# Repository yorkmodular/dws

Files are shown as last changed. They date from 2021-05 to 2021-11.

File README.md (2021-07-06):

## DWS - The Diodular Wave Strangler

Proof, if any were needed, that you don't always need a ton of components to make a boring old sine (or triangle, or sawtooth - square waves don't work too well) wave much more interesting. We're going to achieve this with the aid of an op-amp and a bunch of passives (diodes and resistors, mainly)

Here you'll find:

- The Bill of Materials (BOM) - these are the bits you'll need to complete the module.
- The schematic
- Design files for the front panel, should you be seized with a desire to roll your own.

### In use

Twiddle the knobs.

Seriously.

The effectiveness of each of the diode stage pots seems to depend a lot on the settings of the SCALE and SLOPE pots - in some cases, you'll find that only the first four stages have any real effect, whereas in others the later stages will have quite a profound effect instead. Experimentation is the key.

I find that the best results can be obtained from sine and triangle waves, whereas the effects on square waves are minimal at best. The effects on a sawtooth are somewhere in between - in any event, a bit of post-filtering can work wonders for the sound.

A good starting point would be to have the SCALE pot fully counter-clockwise and the SLOPE pot at around 10 o'clock - when adjusting the levels in the diode stages, try and avoid consecutive 'extreme' values.

### Build notes

The build is pretty straightforward - there are no surface-mount or wilfully strange parts, unless you count Schottky diodes.

* R20 can either be a 1k resistor _or_ a 100nF film capacitor. The latter will remove any DC offset in the folded signal - this is what I recommend (ceramic capacitors will work, but I prefer to use film caps for DC offset removal purposes)

* I strongly recommend using Schottky (or germanium) diodes for both the diode stages (D1-D8) and the soft-clipping section (D10, D11) - ideally, the voltage drop for these diodes should be no more than 0.3V - for pre-built modules I use Vishay SD101C-TR diodes, but any small-signal Schottky will do. It's OK to use 1N4148s for the power supply diodes (D13, D14)

* In terms of pots, RV1 to RV8 should be 100k audio taper - linear taper will work fine, but I found that the log taper pots gave me more control. SCALE1 and SLOPE1 pots should be linear taper (10k and 100k, respectively), whilst the OUTPUT_GAIN pot should be 100k audio.

* Reduce the value of R19 if you want more gain.

* The op-amp doesn't need to be anything particularly exotic - I generally use TL084s on pre-builts. TL074 will work just as well.

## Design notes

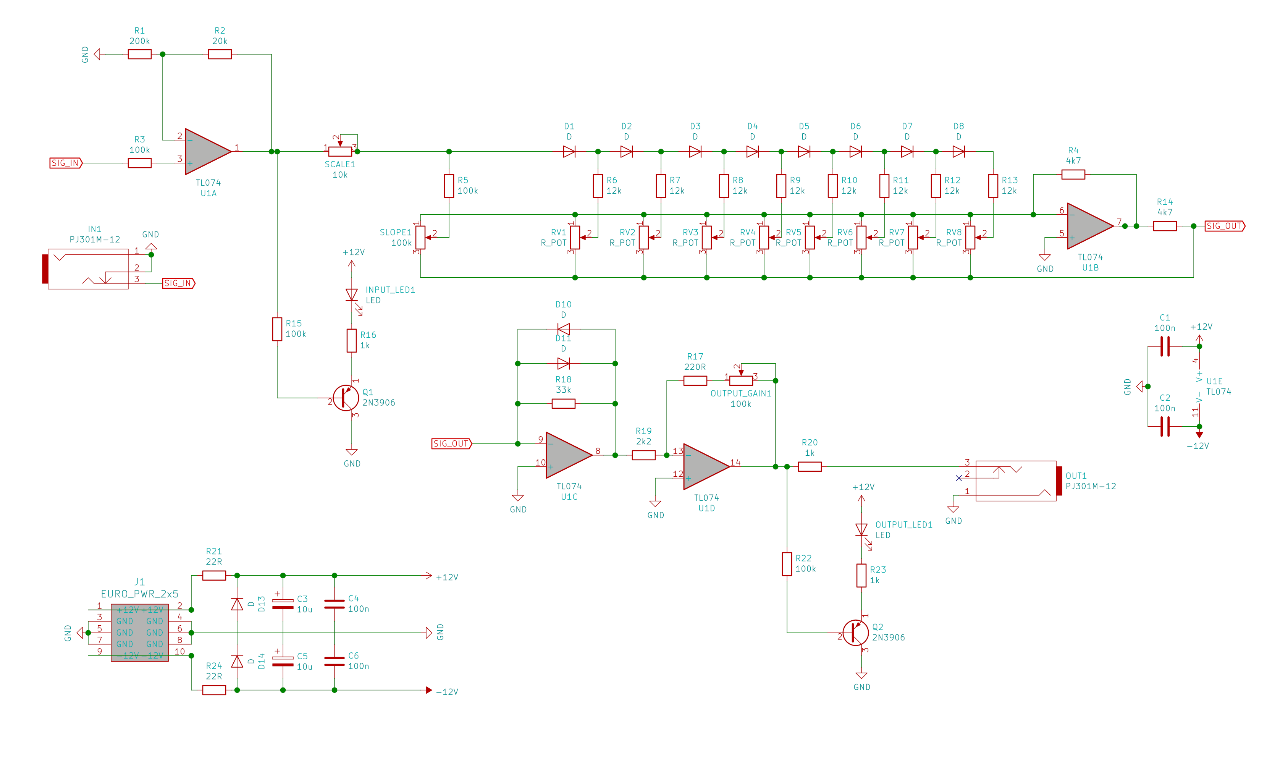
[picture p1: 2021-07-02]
dws-schematic.png

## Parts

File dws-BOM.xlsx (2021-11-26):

Reference | Quantity | Value
C1 C2 C4 C6 | 4 | 100n
C3 C5 | 2 | 10u
D1 D2 D3 D4 D5 D6 D7 D8 D10 D11 D13 D14 | 12 |  | For best results, D1-D8 should be Schottky diodes. 1N4148s for all the others
INPUT_LED1 OUTPUT_LED1 | 2 | LED
J1 | 1 | EURO_PWR_2x5
OUT1 IN1 | 2 | PJ301M-12
OUTPUT_GAIN1 | 1 | A100k
SLOPE1 | 1 | B100k
Q1 Q2 | 2 | 2N3906
R1 | 1 | 200k
R4 R14 | 2 | 4k7
R16 R23 | 3 | 1k
R17 | 1 | 220R
R18 | 1 | 33k
R19 | 1 | 2k2
R2 | 1 | 20k
R21 R24 | 2 | 22R
R3 R5 R15 R22 | 4 | 100k
R6 R7 R8 R9 R10 R11 R12 R13 | 8 | 12k
RV1 RV2 RV3 RV4 RV5 RV6 RV7 RV8 | 8 | 100k | Audio or linear taper – audio preferred
SCALE1 | 1 | B10k
U1 | 1 | TL074
R20 | 1 | 1k OR 100nF film cap | (Capacitor recommended to remove any DC offset in the output)

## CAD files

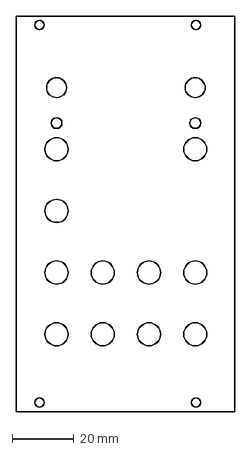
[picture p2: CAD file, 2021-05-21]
panels/dws-panel.dxf
70.8 x 128.4 mm

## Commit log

2021-07-02 Fix value of SCALE pot
    [dws-BOM.xlsx]
2021-07-02 Updated schematic image
2021-11-26 Updated BOM
    [dws-BOM.xlsx]
2023-10-20 Add interactive BOM
2023-10-20 Add mainboard Gerber files
2023-10-20 Add front-panel Gerber files
